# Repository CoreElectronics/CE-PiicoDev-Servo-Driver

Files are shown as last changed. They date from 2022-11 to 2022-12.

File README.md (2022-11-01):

# PiicoDev® Servo Driver

This is the repo for the Core Electronics [PiicoDev Servo Driver](https://core-electronics.com.au/catalog/product/view/sku/CE09181) PCB project.

## License
This project is open source - please review the LICENSE.md file for further licensing information.

If you have any technical questions, or concerns about licensing, please contact technical support on the [Core Electronics forums](https://forum.core-electronics.com.au/).

*\"PiicoDev\" and the PiicoDev logo are trademarks of Core Electronics Pty Ltd.*

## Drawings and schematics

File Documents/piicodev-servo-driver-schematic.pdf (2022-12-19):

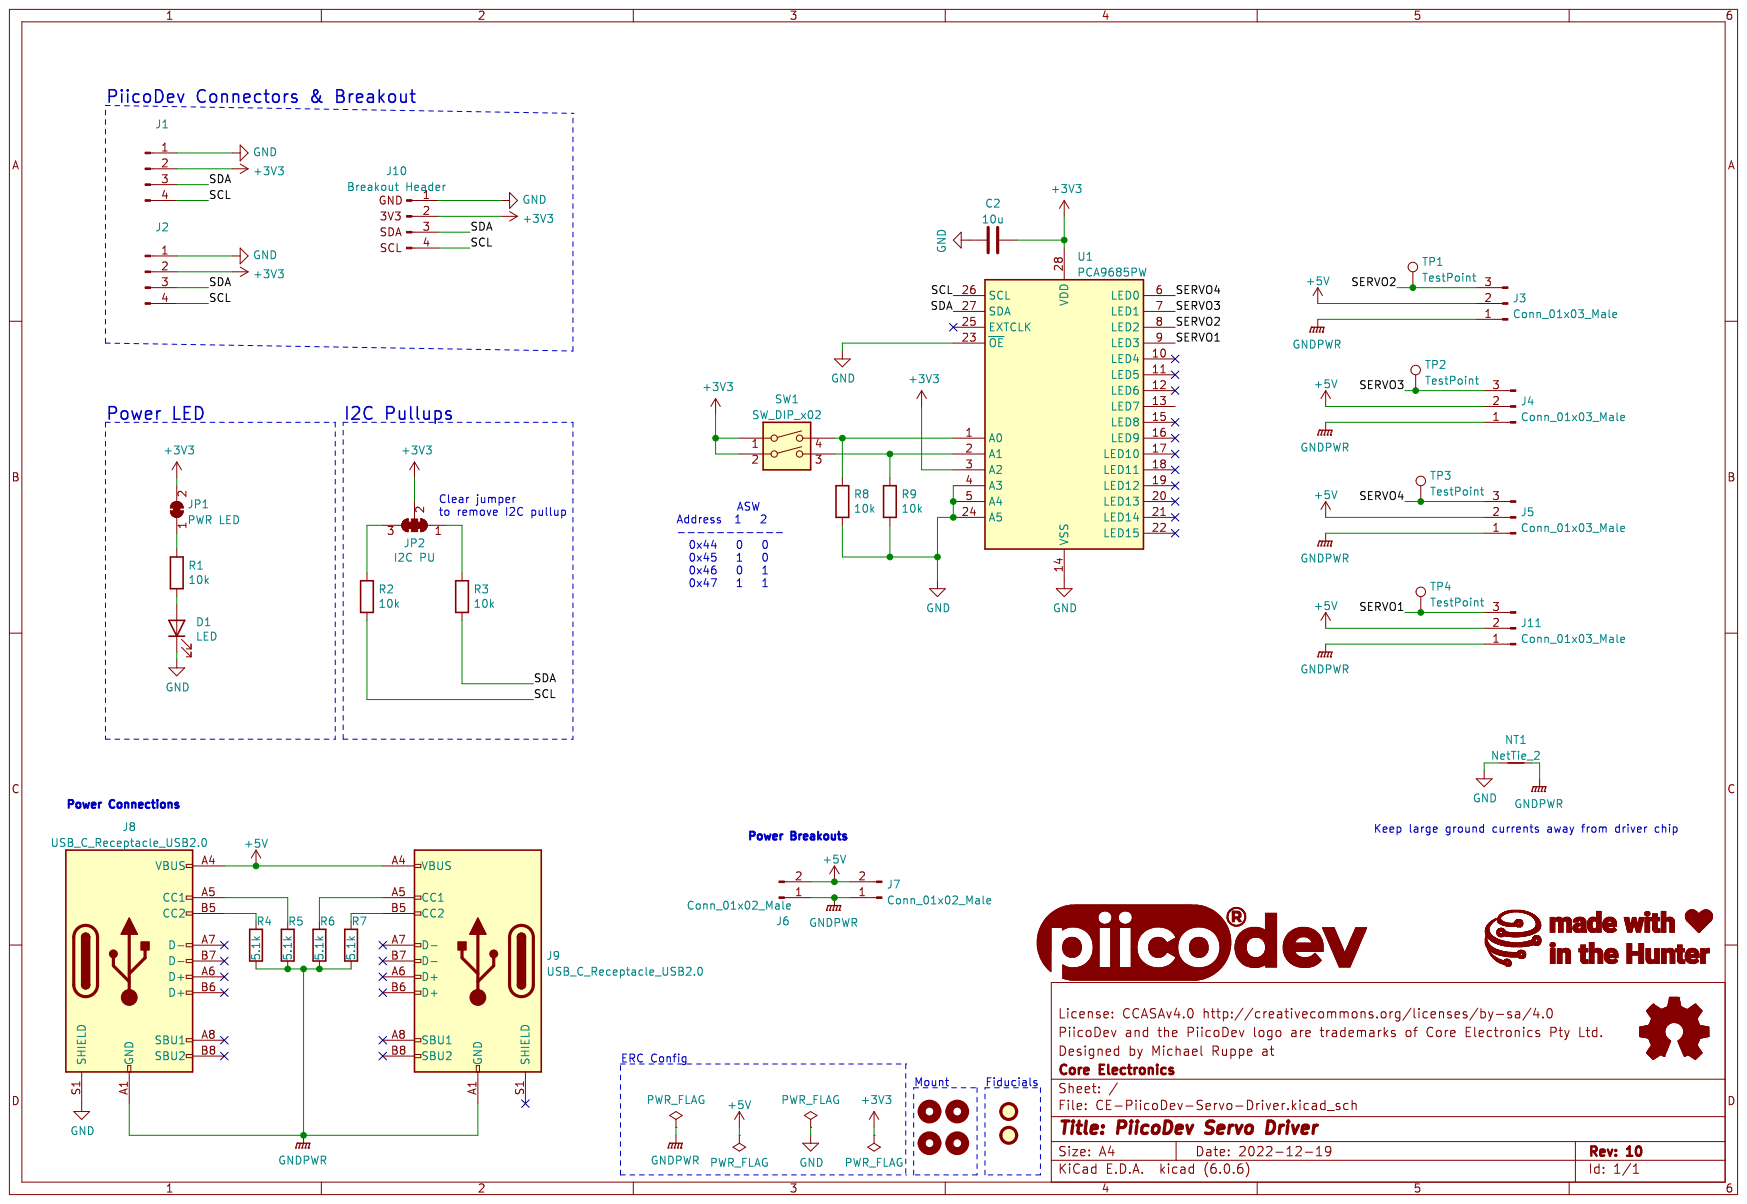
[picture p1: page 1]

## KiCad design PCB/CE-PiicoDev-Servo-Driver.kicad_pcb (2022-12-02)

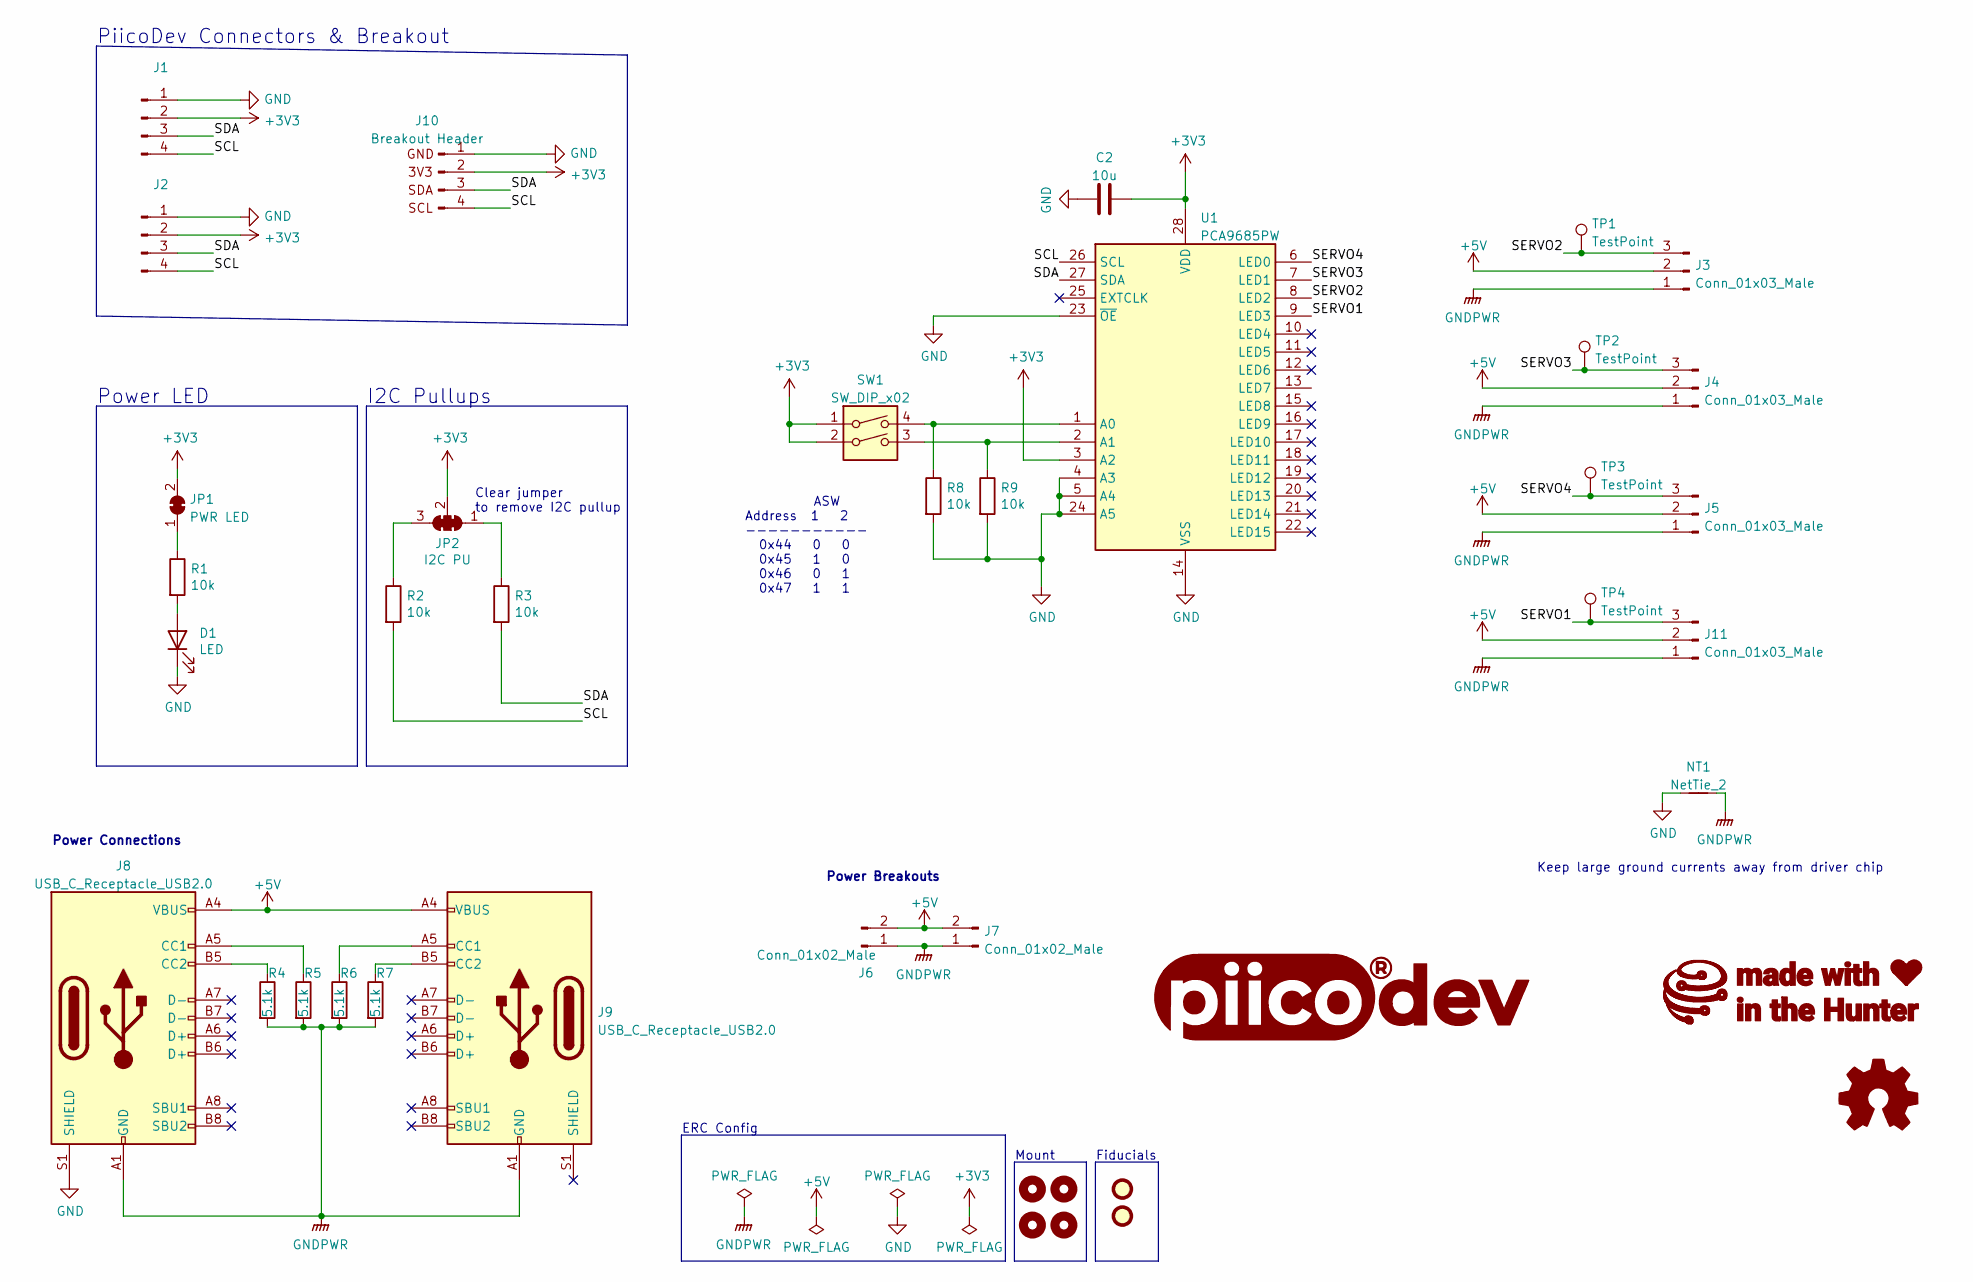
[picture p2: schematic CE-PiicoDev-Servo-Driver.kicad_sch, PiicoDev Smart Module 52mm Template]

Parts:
C2: 10u; C_0603_1608Metric
D1: LED; LED_0603_1608Metric
FID1, FID2: Fiducial; Fiducial_1mm_Mask2mm
G1: LOGO_PiicoDev; piicodev_logo_14.2x3.4mm
G2: LOGO_CoreElectronics_no-text; CoreElectronics_logo_5mm_v2
G3: LOGO_made-with-love; piicodev_logo_14.2x3.4mm
H1, H2, H3, H4: MountingHole; MountingHole_2.7mm_M2.5_PadClearance_1.2
J1, J2: JST_SH_SM04B-SRSS-TB_1x04-1MP_P1.00mm_Horizontal
J3, J4, J5, J11: Conn_01x03_Male; PinHeader_1x03_P2.54mm_Vertical_SMD_Pin1Left
J6, J7: Conn_01x02_Male; PinHeader_1x02_P2.54mm_Vertical
J8, J9: USB_C_Receptacle_USB2.0; USB_C_Receptacle_HRO_TYPE-C-31-M-12-with-paste
J10: Breakout Header; PiicoDev_header_4pin
JP1: PWR LED; SolderJumper-2_P1.3mm_Bridged_RoundedPad1.0x1.5mm
JP2: I2C PU; SolderJumper-3_P1.3mm_Closed_RoundedPad1.0x1.5mm_NumberLabe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
LOGO1: Logo_Open_Hardware_Small; oshw
NT1: NetTie_2; NetTie-2_SMD_Pad2.0mm
R1, R2, R3, R8, R9: 10k; R_0402_1005Metric
R4, R5, R6, R7: 5.1k; R_0402_1005Metric
SW1: SW_DIP_x02; SW_DIP_x02_Slide_CHS-02A1
TP1, TP2, TP3, TP4: TestPoint; TestPoint_Pad_D1.0mm
U1: PCA9685PW; TSSOP-28_4.4x9.7mm_P0.65mm

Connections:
+3V3: C2.1, J1.2, J2.2, J10.2, JP1.2 (B), JP2.2 (C), SW1.1, SW1.2, U1.3 (A2), U1.28 (VDD)
+5V: J3.2, J4.2, J5.2, J6.2, J7.2, J8.A4 (VBUS), J8.A9 (VBUS), J8.B4 (VBUS), J8.B9 (VBUS), J9.A4 (VBUS), J9.A9 (VBUS), J9.B4 (VBUS), J9.B9 (VBUS), J11.2
/SCL: J1.4, J2.4, J10.4, R2.2, U1.26 (SCL)
/SDA: J1.3, J2.3, J10.3, R3.2, U1.27 (SDA)
/SERVO1: J11.3, TP4.1, U1.9 (LED3)
/SERVO2: J3.3, TP1.1, U1.8 (LED2)
/SERVO3: J4.3, TP2.1, U1.7 (LED1)
/SERVO4: J5.3, TP3.1, U1.6 (LED0)
GND: C2.2, D1.1 (K), J1.1, J2.1, J8.S1 (SHIELD), J10.1, NT1.1, R8.2, R9.2, U1.4 (A3), U1.5 (A4), U1.14 (VSS), U1.23 (~OE), U1.24 (A5)
GNDPWR: J3.1, J4.1, J5.1, J6.1, J7.1, J8.A1 (GND), J8.A12 (GND), J8.B1 (GND), J8.B12 (GND), J9.A1 (GND), J9.A12 (GND), J9.B1 (GND), J9.B12 (GND), J11.1, NT1.2, R4.2, R5.2, R6.2, R7.2
unnamed: D1.2 (A), R1.2
unnamed: J8.A5 (CC1), R5.1
unnamed: J8.B5 (CC2), R4.1
unnamed: J9.A5 (CC1), R6.1
unnamed: J9.B5 (CC2), R7.1
unnamed: JP1.1 (A), R1.1
unnamed: JP2.1 (A), R3.1
unnamed: JP2.3 (B), R2.1
unnamed: R8.1, SW1.4, U1.1 (A0)
unnamed: R9.1, SW1.3, U1.2 (A1)

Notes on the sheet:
PiicoDev Connectors & Breakout
I2C Pullups
Keep large ground currents away from driver chip
Power LED
Power Connections
Mount
Clear jumper to remove I2C pullup
Power Breakouts
ERC Config
Fiducials
ASW Address 1 2 ----------- 0x44 0 0 0x45 1 0 0x46 0 1 0x47 1 1

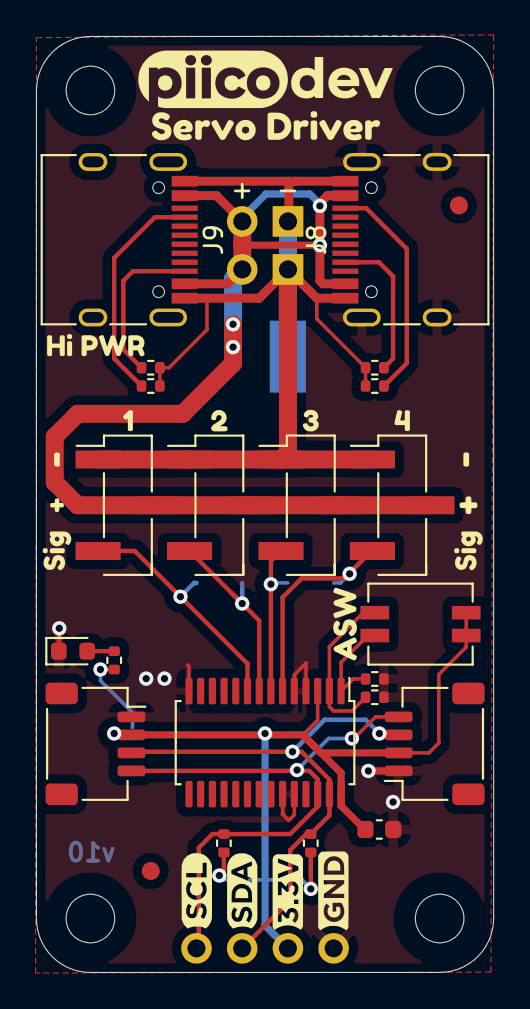
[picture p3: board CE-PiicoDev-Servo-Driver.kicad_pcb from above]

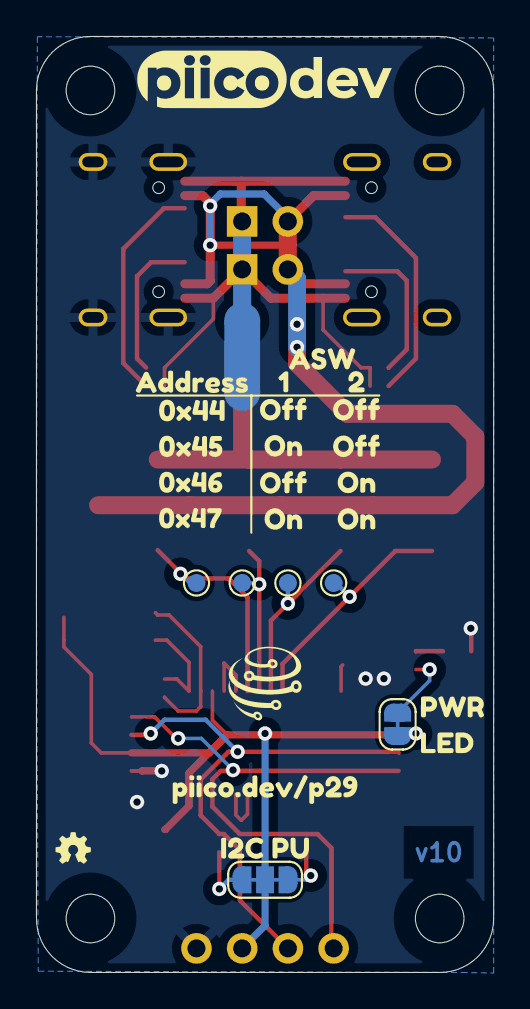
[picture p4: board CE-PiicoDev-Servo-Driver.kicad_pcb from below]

Board: 2 copper layers, 25.4 x 52.0 mm, 70 parts (26 on the bottom side), 20 nets.

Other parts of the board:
kibuzzard-637AE2C2: G***; kibuzzard-637AE2C2
kibuzzard-637AE2C9: G***; kibuzzard-637AE2C9
kibuzzard-637AE2D0: G***; kibuzzard-637AE2D0
kibuzzard-637AE2D7: G***; kibuzzard-637AE2D7
kibuzzard-637AE5E5: G***; kibuzzard-637AE5E5
kibuzzard-637AE34A: G***; kibuzzard-637AE34A
kibuzzard-637AE45C: G***; kibuzzard-637AE45C
kibuzzard-637AE58B, kibuzzard-637AE58B#2, kibuzzard-637AE58B#3, kibuzzard-637AE58B#4: G***; kibuzzard-637AE58B
kibuzzard-637AE425: G***; kibuzzard-637AE425
kibuzzard-637AE445: G***; kibuzzard-637AE445
kibuzzard-637AE519: G***; kibuzzard-637AE519
kibuzzard-637AE520: G***; kibuzzard-637AE520
kibuzzard-637AE527: G***; kibuzzard-637AE527
kibuzzard-637AE581, kibuzzard-637AE581#2, kibuzzard-637AE581#3, kibuzzard-637AE581#4: G***; kibuzzard-637AE581
kibuzzard-637AEE57: G***; kibuzzard-637AEE57
kibuzzard-637AF282: G***; kibuzzard-637AF282
kibuzzard-637721F3: G***; kibuzzard-637721F3
kibuzzard-6360811E: G***; kibuzzard-6360811E
kibuzzard-6360812A: G***; kibuzzard-6360812A
kibuzzard-6377139C: G***; kibuzzard-6377139C
kibuzzard-63608105: G***; kibuzzard-63608105
kibuzzard-63771600, kibuzzard-63771600#2: G***; kibuzzard-63771600

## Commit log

2022-11-01 initial commit v00
    [CE-PiicoDev-Servo-Driver.kicad_pcb, CE-PiicoDev-Servo-Driver.kicad_sch]
2022-12-02 include paste on USB connector support tabs
    [CE-PiicoDev-Servo-Driver.kicad_pcb, CE-PiicoDev-Servo-Driver.kicad_sch]

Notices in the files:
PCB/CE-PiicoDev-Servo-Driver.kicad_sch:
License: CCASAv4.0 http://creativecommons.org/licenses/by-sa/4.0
